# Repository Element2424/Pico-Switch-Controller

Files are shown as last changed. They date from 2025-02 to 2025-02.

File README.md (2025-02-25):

# Pico-USB-Game-Pad-Switch-Controller
DIY Nintendo Switch (and other systems) controller on a Raspberry Pi Pico

## Table of Contents

- [Description](#description)
- [Features](#features)
- [Hardware Limitations](#hardware-limitations)
- [Inspiration](#inspiration)
- [Setup](#setup)
- [Credits](#credits)

---

## Description

This code allows a Raspberry Pi Pico to control a Nintendo Switch (or other console) using button and joystick inputs connected to the Pico's GPIO pins. Once you have the Pico and the code it can be used for a multitude of things. You can edit the code or if that is not a strong point connect the Pico to an other microcontroller to automate mind-numbing tasks in games like shiny hunting in Pokemon, or jumping rope in Mario, ect. If you have access to a 3d printer you can make your own controller or arcade fight stick. I designed and had PCB made for this but it can just as easily be done on proto board and hand soldering wires. This could be use to built cheep easy custom controllers for anyone. I know just enough to get by and used a lot of resources and the projects of others that I will provide links to, so don't criticize the code too harshly. 

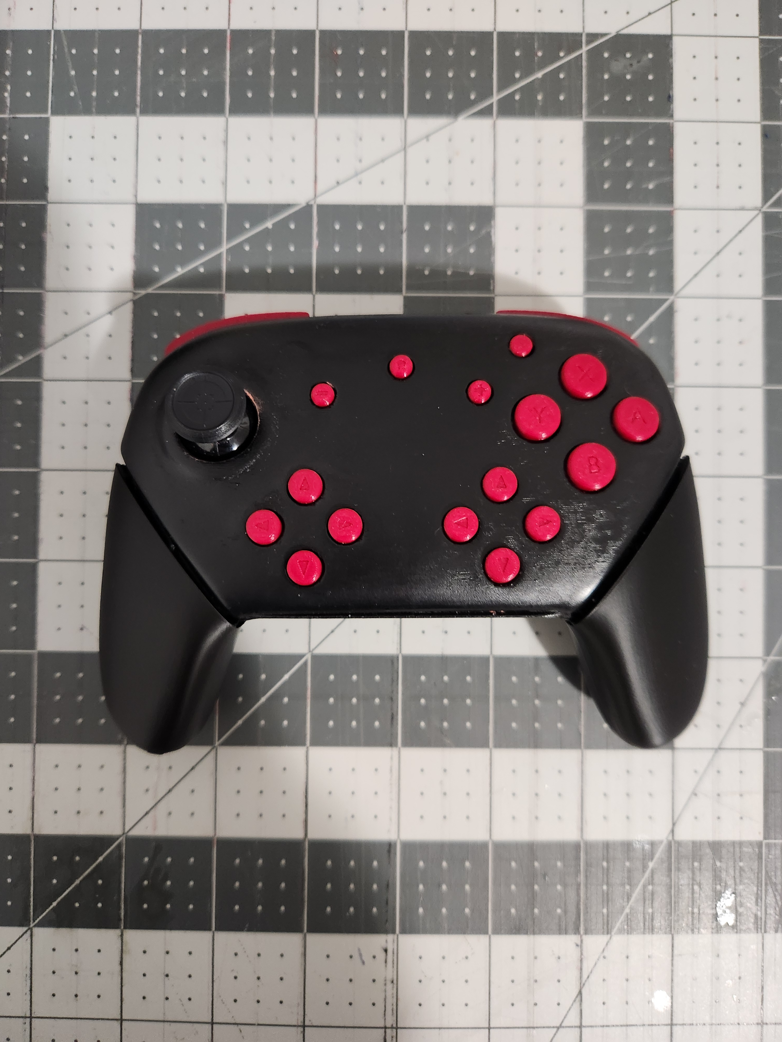
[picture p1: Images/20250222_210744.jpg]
 

## Features

Feature list for this project
- Connects to a Nintendo Switch via USB.
- Will also work on any platform that supports a USB game pad (although some of the buttons may not translate over in the same configuration)
- Fast input responce time for fighting games
- Set up can be as easy as draging and drropping the .uf2 file on to a Pico.
- Scalable inputs for the Left analog stick that can be adjusted to personal preference or to overcome hardware limitations.

## Hardware Limitations

The Pico has 4 analog inputs. Initially I thought this would be great two for the Left Analog Stick X and Y axis, and two for the Right Analog Stick X and Y axis. However it turns out that one of the analog inputs is internal to the RP2040 chip on the Pico and used to read a thermistor. So I was limited to only 3 analog inputs. I choose to use 2 of them for the Left Analog Stick and for the Right Analog Stick I just made them digital buttons. That is not a great solution but was good enough for what I was planning to do. If anyone is feeling ambitious there are extra pins that could be tied to a ADC and read in.

## Inspiration

There have been a lot of things in games that I have thought “It would be nice if this could be automated.” So I started looking around to see if that has been done before. I found a few similar projects that utilize a Teensy board microcontroller to basically do the same thing as this one. Always thought the idea was fun but never wanted to spend the money for one. Not that they are all that expensive but the Pico is 1/4th the cost.  I was able to build a functioning controller for less than 15$ that is less than the cost of a Teensy. I have included a list of parts that I used below. 

- SC0915 Pico 4$
- THB001P Analog Stick 2$
- PTS526SK15SMTR2 LFS Push Buttons 0.13$ x12
- 431256038716 Right Angle Push Button 0.52$ x4

## Setup

To program the Raspberry Pi Pico

1. Hold down the boot sel button on the Pico, and while holding, plug it into your PC via Micro USB cable. (after it has been plugged in you no longer need to hold the boot sel button)
2. Open the Pico in your File Explorer.
3. Download the .uf2 file from this project
4. Drag and drop the .uf2 file to the Pico folder from step 2.
5. Now if you use the the USB cable to connect the Pico to any computer or Nintendo Switch it should register as a controller. That can be tested [here](https://hardwaretester.com/gamepad).
7. Now all that is left is to wire up buttons to the GPIO pins on the Pico and if you want print/build an enclosure for it.

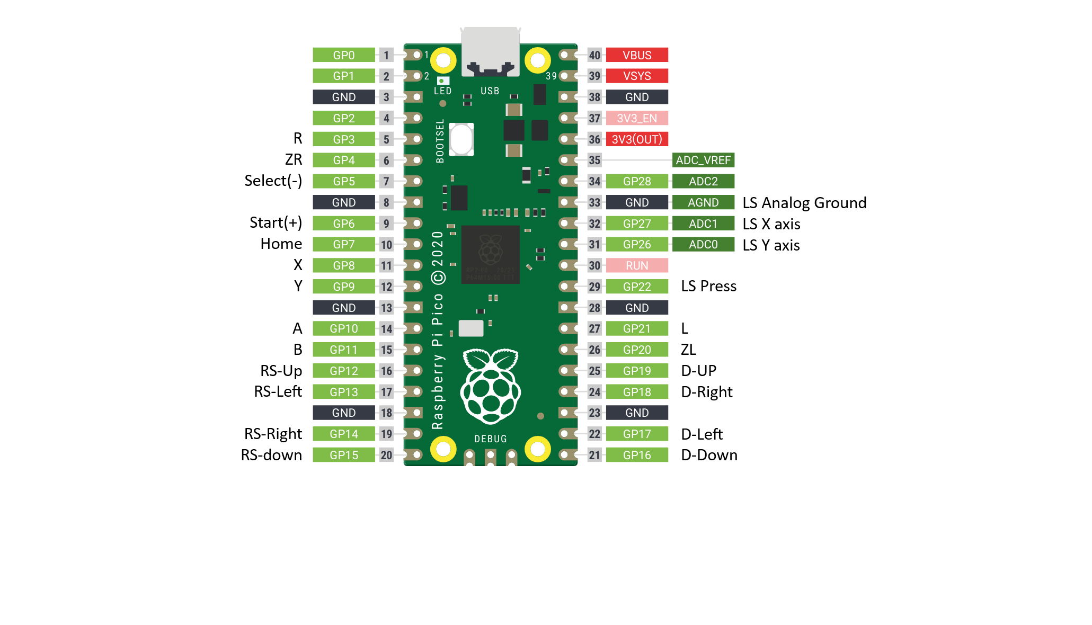
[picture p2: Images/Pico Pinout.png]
 
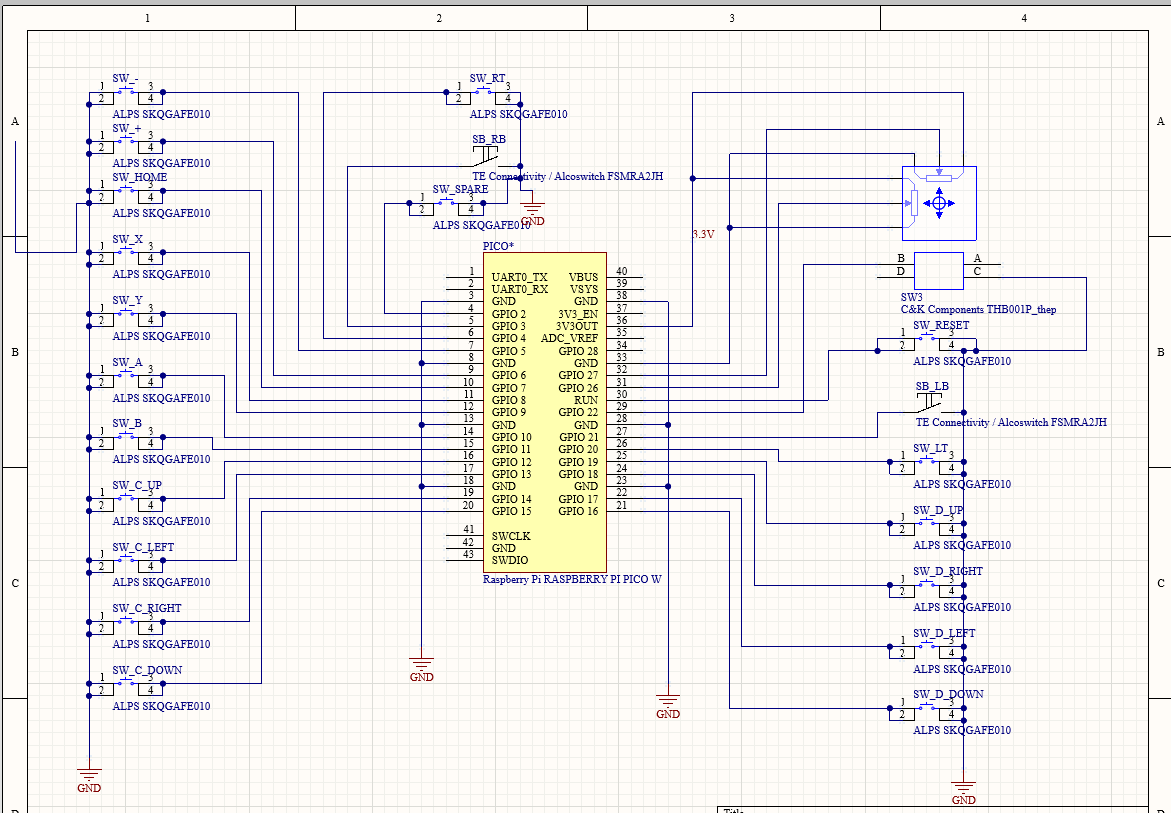
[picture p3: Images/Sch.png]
 

For the left analog stick you should wire the 3.3(Out) (Pin 36) to one end of the analog stick X and Y potentiometers, and the analog ground (pin 33) to the other. Then you should connect the X and Y pins (32 and 31) to their respective wipers.

For all of the other buttons they are set with an internal pull up resistor, this means that you just need to connect their pins to any ground pin to activate them.

I have included the Gerber files that I used to produce the PCB here as well for any who want them. There is also an image of the schematic I used if any want to make their own.

All of the files if you want to 3D print a controller shell and buttons can be found [on my Makerworld upload](https://makerworld.com/en/models/1141897#profileId-1144420), you may have to make an account to download them but they are all free. All of the assembly instructions will be over there as well. The files were too large to upload here. 

If you would like to edit the code I have included all of the source code use to build the .uf2 file as well as the make files that were used. I was using the pico visual studio platform on a windows machine. 

I am more active on my Maker world account, that would be the best place to reach out with questions. 

## Credits 
A lot of the work was already done on the the [Retro Pico Switch](https://github.com/DavidPagels/retro-pico-switch) project. I used this as my starting point, along with the creators and contributors of [TinyUsb](https://github.com/hathach/tinyusb), the [GP2040-CE](https://github.com/OpenStickCommunity/GP2040-CE) project, and the [MPG](https://github.com/OpenStickCommunity/MPG) project.

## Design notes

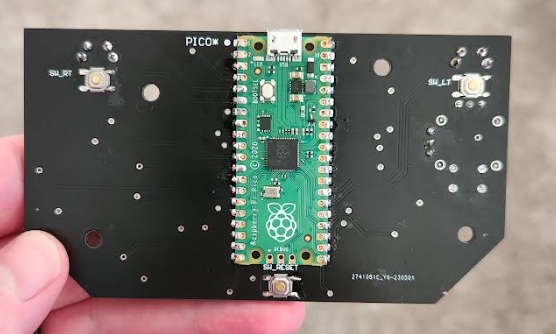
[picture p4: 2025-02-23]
Images/PCB Bottom.png

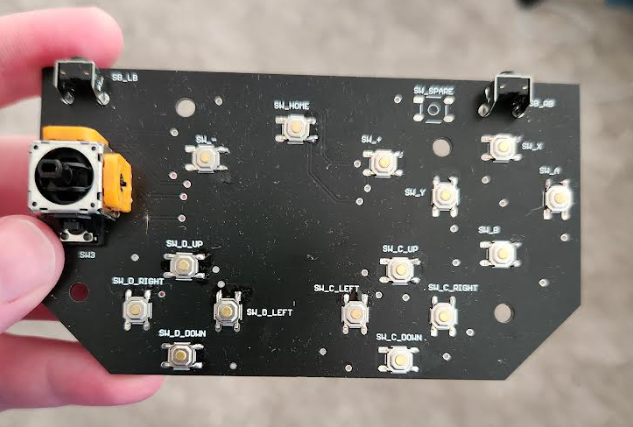
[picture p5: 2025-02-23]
Images/PCB Top.png

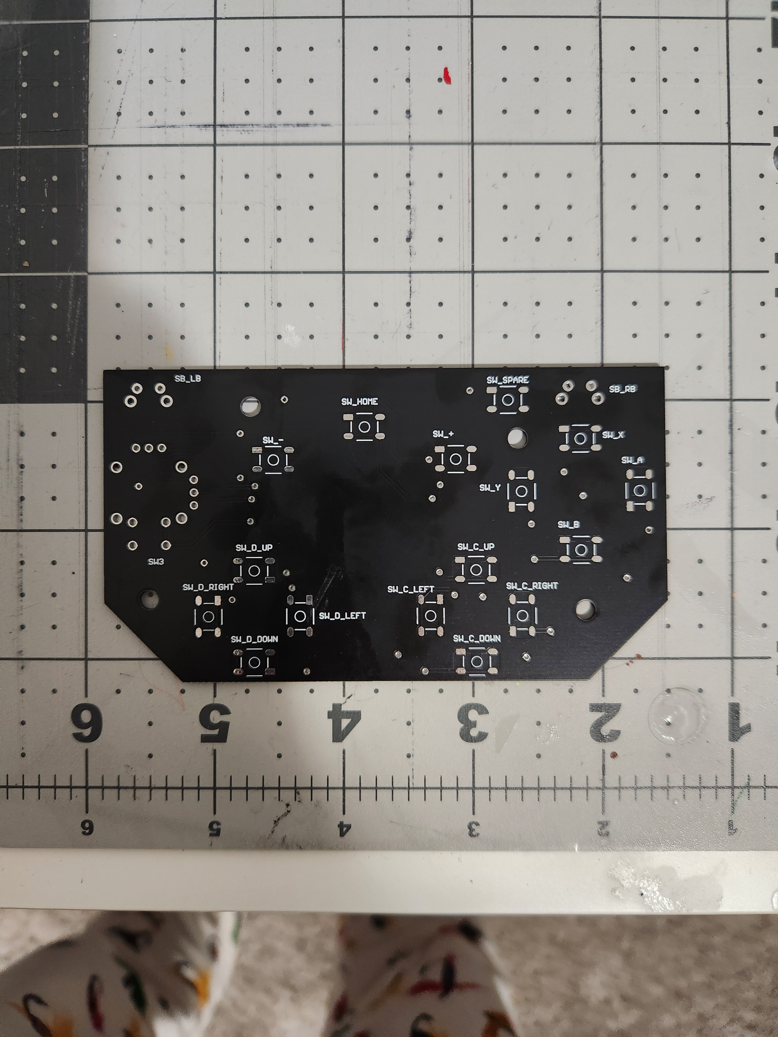
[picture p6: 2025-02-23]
Images/Empty PCB Top.jpg

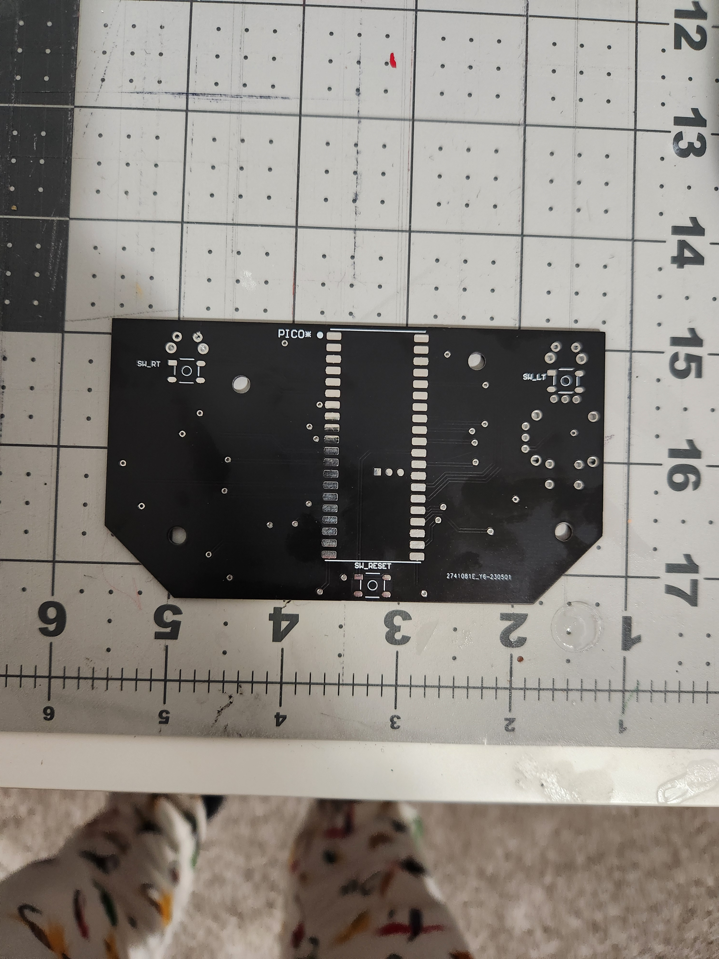
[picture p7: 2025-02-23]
Images/Empty PCB Bottom.jpg

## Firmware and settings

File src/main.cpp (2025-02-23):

#include <stdio.h>
#include <string.h>

#include "GamecubeController.h"
#include "N64Controller.h"
#include "SwitchController.h"
#include "pico/stdlib.h"

#ifdef SWITCH_BLUETOOTH
#include "SwitchBluetooth.h"
#else
#include "SwitchUsb.h"
#endif

#ifdef CONTROLLER_TYPE
#define controllerType CONTROLLER_TYPE
#else
#define controllerType "Switch"
#endif

int main() {
  stdio_init_all();

  Controller *controller;



  if (strcmp(controllerType, "N64") == 0) {
    controller = new N64Controller(18);
  } else if (strcmp(controllerType, "Gamecube") == 0) {
    controller = new GamecubeController(18);
  } else if (strcmp(controllerType, "Switch") == 0) {
    controller = new SwitchController(18);
  }
  controller->init();

#ifdef SWITCH_BLUETOOTH
  SwitchBluetooth::init(controller);
#else
  SwitchUsb switchUsb(controller);
  switchUsb.init();
#endif
}

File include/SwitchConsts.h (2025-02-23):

#ifndef SwitchConsts_h
#define SwitchConsts_h

#include "pico/stdlib.h"

typedef struct __attribute((packed, aligned(1))) {
  uint16_t buttons;
  uint8_t hat;
  uint8_t lx;
  uint8_t ly;
  uint8_t rx;
  uint8_t ry;
  uint8_t vendor;
} SwitchUsbReport;

// HAT report (4 bits)
/*                                  I think the left and right are wrong this is the orginal // Update I was right, at least for the switch these are backwards at least if you are looking at the conntroller
#define SWITCH_USB_HAT_UP 0x00
#define SWITCH_USB_HAT_UPRIGHT 0x01
#define SWITCH_USB_HAT_RIGHT 0x02
#define SWITCH_USB_HAT_DOWNRIGHT 0x03
#define SWITCH_USB_HAT_DOWN 0x04
#define SWITCH_USB_HAT_DOWNLEFT 0x05
#define SWITCH_USB_HAT_LEFT 0x06
#define SWITCH_USB_HAT_UPLEFT 0x07
#define SWITCH_USB_HAT_NOTHING 0x08
*/

#define SWITCH_USB_HAT_UP 0x00
#define SWITCH_USB_HAT_UPRIGHT 0x07
#define SWITCH_USB_HAT_RIGHT 0x06
#define SWITCH_USB_HAT_DOWNRIGHT 0x05
#define SWITCH_USB_HAT_DOWN 0x04
#define SWITCH_USB_HAT_DOWNLEFT 0x03
#define SWITCH_USB_HAT_LEFT 0x02
#define SWITCH_USB_HAT_UPLEFT 0x01
#define SWITCH_USB_HAT_NOTHING 0x08

// Button report (16 bits)
#define SWITCH_USB_MASK_Y (1U << 0)
#define SWITCH_USB_MASK_B (1U << 1)
#define SWITCH_USB_MASK_A (1U << 2)
#define SWITCH_USB_MASK_X (1U << 3)
#define SWITCH_USB_MASK_L (1U << 4)
#define SWITCH_USB_MASK_R (1U << 5)
#define SWITCH_USB_MASK_ZL (1U << 6)
#define SWITCH_USB_MASK_ZR (1U << 7)
#define SWITCH_USB_MASK_MINUS (1U << 8)
#define SWITCH_USB_MASK_PLUS (1U << 9)
#define SWITCH_USB_MASK_L3 (1U << 10)
#define SWITCH_USB_MASK_R3 (1U << 11)
#define SWITCH_USB_MASK_HOME (1U << 12)
#define SWITCH_USB_MASK_CAPTURE (1U << 13)

// Switch analog sticks only report 8 bits
#define SWITCH_USB_JOYSTICK_MIN 0x00
#define SWITCH_USB_JOYSTICK_MID 0x80
#define SWITCH_USB_JOYSTICK_MAX 0xFF

static const uint8_t switch_usb_string_language[] = {0x09, 0x04};
static const uint8_t switch_usb_string_manufacturer[] = "PICO SWITCH PRO.";
static const uint8_t switch_usb_string_product[] = "J24 CONTROLLER";
static const uint8_t switch_usb_string_version[] = "1.0";

static const uint8_t *switch_usb_string_descriptors[] = {
    switch_usb_string_language, switch_usb_string_manufacturer,
    switch_usb_string_product, switch_usb_string_version};

static const uint8_t switch_usb_device_descriptor[] = {
    0x12,        // bLength
    0x01,        // bDescriptorType (Device)
    0x00, 0x02,  // bcdUSB 2.00
    0x00,  // bDeviceClass (Use class information in the Interface Descriptors)
    0x00,  // bDeviceSubClass
    0x00,  // bDeviceProtocol
    0x40,  // bMaxPacketSize0 64
    0x0D, 0x0F,  // idVendor 0x0F0D
    0x92, 0x00,  // idProduct 0x92
    0x00, 0x01,  // bcdDevice 2.00
    0x01,        // iManufacturer (String Index)
    0x02,        // iProduct (String Index)
    0x00,        // iSerialNumber (String Index)
    0x01,        // bNumConfigurations 1
};

static const uint8_t switch_usb_hid_descriptor[] = {
    0x09,        // bLength
    0x21,        // bDescriptorType (HID)
    0x11, 0x01,  // bcdHID 1.11
    0x00,        // bCountryCode
    0x01,        // bNumDescriptors
    0x22,        // bDescriptorType[0] (HID)
    0x56, 0x00,  // wDescriptorLength[0] 86
};

static const uint8_t switch_usb_configuration_descriptor[] = {
    0x09,        // bLength
    0x02,        // bDescriptorType (Configuration)
    0x29, 0x00,  // wTotalLength 41
    0x01,        // bNumInterfaces 1
    0x01,        // bConfigurationValue
    0x00,        // iConfiguration (String Index)
    0x80,        // bmAttributes
    0xFA,        // bMaxPower 500mA

    0x09,  // bLength
    0x04,  // bDescriptorType (Interface)
    0x00,  // bInterfaceNumber 0
    0x00,  // bAlternateSetting
    0x02,  // bNumEndpoints 2
    0x03,  // bInterfaceClass
    0x00,  // bInterfaceSubClass
    0x00,  // bInterfaceProtocol
    0x00,  // iInterface (String Index)

    0x09,        // bLength
    0x21,        // bDescriptorType (HID)
    0x11, 0x01,  // bcdHID 1.11
    0x00,        // bCountryCode
    0x01,        // bNumDescriptors
    0x22,        // bDescriptorType[0] (HID)
    0x56, 0x00,  // wDescriptorLength[0] 86

    0x07,        // bLength
    0x05,        // bDescriptorType (Endpoint)
    0x02,        // bEndpointAddress (OUT/H2D)
    0x03,        // bmAttributes (Interrupt)
    0x40, 0x00,  // wMaxPacketSize 64
    0x01,        // bInterval 1 (unit depends on device speed)

    0x07,        // bLength
    0x05,        // bDescriptorType (Endpoint)
    0x81,        // bEndpointAddress (IN/D2H)
    0x03,        // bmAttributes (Interrupt)
    0x40, 0x00,  // wMaxPacketSize 64
    0x01,        // bInterval 1 (unit depends on device speed)
};
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

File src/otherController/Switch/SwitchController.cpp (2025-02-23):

#include "SwitchController.h"

#include "Controller.pio.h"
#include "pico/stdlib.h"

//below this are my includes
#include <stdio.h>
#include "pico.h"
#include "hardware/structs/adc.h"
//#include "pico/stdlib.h"
#include "hardware/gpio.h"
#include "hardware/adc.h"



void SwitchController::init() {
  // init led pin and set it to an outpit
    gpio_init(LED_PIN);
    gpio_set_dir(LED_PIN, GPIO_OUT);

    //init all of the digital input button pins and have them be pulled high by defalt
    for(int i = 0; i <= 22; i++){
        gpio_init(i);
        gpio_set_dir(i, GPIO_IN);
        gpio_pull_up(i);
    }
    
    adc_init(); //init adc functionality
    adc_gpio_init(ANALOG_X_PIN); // sets gpio as high impedance, no pullups ect
    //adc_select_input(0); // selects adc0 for analog X 
    adc_gpio_init(ANALOG_Y_PIN); // sets gpio as high impedance, no pullups ect
    //adc_select_input(1);  // selects adc1 for analog Y

    sleep_us(200); // not sure if this is needed
    
}

void SwitchController::ReadPins(){
   
}

void SwitchController::updateState() {
  //reads and stores all of the digitial GIOP pins 
  _ButtonReport = ~gpio_get_all(); // inverted because the pins are pulled high
  
  // reads and stores the values for the left stick analog values
  adc_select_input(0); // selects adc0 for analog X 
  _LS_X = adc_read();
  adc_select_input(1); // selects adc1 for analog Y 
  _LS_Y = adc_read();

}

void SwitchController::getSwitchUsbReport(SwitchUsbReport *switchUsbReport) {

  updateState();
  gpio_put(LED_PIN, false);
 // if(SWITCH_C_MASK & _ButtonReport ){gpio_put(LED_PIN, true);}
  if(PIN_MASK_2 & _ButtonReport ){gpio_put(LED_PIN, true);}

  switchUsbReport->hat = SWITCH_USB_HAT_NOTHING;
  switchUsbReport->rx = SWITCH_USB_JOYSTICK_MID;
  switchUsbReport->ry = SWITCH_USB_JOYSTICK_MID;

  /*
  uint16_t test = 3;

  switchUsbReport->buttons = 0;
  gpio_put(led_pin, false);

    if(gpio_get(16) == false){
      switchUsbReport->buttons += 4;
      gpio_put(led_pin, true);
    }
    if (gpio_get(17) == false){
      switchUsbReport->buttons += 2;
      gpio_put(led_pin, true);
    }
    */
  
  // Updating digital buttons 
  switchUsbReport->buttons =
      (PIN_MASK_20 & _ButtonReport ? SWITCH_USB_MASK_ZL : 0) |
      (PIN_MASK_21 & _ButtonReport ? SWITCH_USB_MASK_L : 0) |
      (PIN_MASK_4 & _ButtonReport ? SWITCH_USB_MASK_ZR : 0) |
      (PIN_MASK_3 & _ButtonReport ? SWITCH_USB_MASK_R : 0) |
      (PIN_MASK_9 & _ButtonReport ? SWITCH_USB_MASK_Y : 0) |
      (PIN_MASK_8 & _ButtonReport ? SWITCH_USB_MASK_X : 0) |
      (PIN_MASK_11 & _ButtonReport ? SWITCH_USB_MASK_B : 0) |
      (PIN_MASK_10 & _ButtonReport ? SWITCH_USB_MASK_A : 0) |
      (PIN_MASK_7 & _ButtonReport ? SWITCH_USB_MASK_HOME : 0) |
      (PIN_MASK_5 & _ButtonReport ? SWITCH_USB_MASK_MINUS : 0) |
      (PIN_MASK_6 & _ButtonReport ? SWITCH_USB_MASK_PLUS : 0) |
      (PIN_MASK_22 & _ButtonReport ? SWITCH_USB_MASK_L3 : 0);
      

      
  // Setting D PAD
  switch (SWITCH_DPAD_MASK & _ButtonReport) {
    case SWITCH_DPAD_UP:
      switchUsbReport->hat = SWITCH_USB_HAT_UP;
      break;
    case SWITCH_DPAD_UP_RIGHT:
      switchUsbReport->hat = SWITCH_USB_HAT_UPRIGHT;
      break;
    case SWITCH_DPAD_RIGHT:
      switchUsbReport->hat = SWITCH_USB_HAT_RIGHT;
      break;
    case SWTICH_DPAD_DOWN_RIGHT:
      switchUsbReport->hat = SWITCH_USB_HAT_DOWNRIGHT;
      break;
    case SWITCH_DPAD_DOWN:
      switchUsbReport->hat = SWITCH_USB_HAT_DOWN;
      break;
    case SWITCH_DPAD_DOWN_LEFT:
      switchUsbReport->hat = SWITCH_USB_HAT_DOWNLEFT;
      break;
    case SWITCH_DPAD_LEFT:
      switchUsbReport->hat = SWITCH_USB_HAT_LEFT;
      break;
    case SWITCH_DPAD_UP_LEFT:
      switchUsbReport->hat = SWITCH_USB_HAT_UPLEFT;
      break;
  }
  // Updating C Stick
  //switchUsbReport->rx = SWITCH_USB_JOYSTICK_MID;
  //switchUsbReport->ry = SWITCH_USB_JOYSTICK_MID;
  switch (SWITCH_C_MASK & _ButtonReport) {
    case PIN_MASK_12:
      switchUsbReport->ry = SWITCH_USB_JOYSTICK_MIN;
      break;
    case PIN_MASK_15:
      switchUsbReport->ry = SWITCH_USB_JOYSTICK_MAX;
      break;
    case PIN_MASK_13:
      switchUsbReport->rx = SWITCH_USB_JOYSTICK_MIN;
      break;
    case PIN_MASK_14:
      switchUsbReport->rx = SWITCH_USB_JOYSTICK_MAX;
      break;
  }

  //updating Left Stick

    uint16_t _LS_X_pos = 255-(_LS_Zero_Factor * _LS_Y); // not sure what error lead to these needing to be switched byt x is y and y is x
    uint16_t _LS_Y_pos = 255-(_LS_Zero_Factor * _LS_X);
/*
    if(_LS_X_pos > (SWITCH_USB_JOYSTICK_MID + _LS_Dead_Zone))
    {
      _LS_X_pos = _LS_X_pos * (1 + _LS_X_Scale_Factor_P);
    }

    else if(_LS_X_pos < (SWITCH_USB_JOYSTICK_MID - _LS_Dead_Zone))
    {
      _LS_X_pos = _LS_X_pos * (1 - _LS_X_Scale_Factor_N);
    }

    else {_LS_X_pos = SWITCH_USB_JOYSTICK_MID;}

    if(_LS_Y_pos > (SWITCH_USB_JOYSTICK_MID + _LS_Dead_Zone))
    {
      _LS_Y_pos = _LS_Y_pos * (1 + _LS_Y_Scale_Factor_P);
    }

    else if(_LS_Y_pos < (SWITCH_USB_JOYSTICK_MID - _LS_Dead_Zone))
    {
      _LS_Y_pos = _LS_Y_pos * (1 - _LS_Y_Scale_Factor_N);
    }

    else {_LS_Y_pos = SWITCH_USB_JOYSTICK_MID;}
*/
    if(_LS_X_pos > (SWITCH_USB_JOYSTICK_MID + _LS_Dead_Zone))
    {
      _LS_X_pos = _LS_X_pos + ((_LS_X_pos - SWITCH_USB_JOYSTICK_MID ) * _LS_X_Scale_Factor_P); 
    }
     else if(_LS_X_pos < (SWITCH_USB_JOYSTICK_MID - _LS_Dead_Zone))
    {
      _LS_X_pos = _LS_X_pos + ((_LS_X_pos - SWITCH_USB_JOYSTICK_MID) * _LS_X_Scale_Factor_N); 
    }
    else {_LS_X_pos = SWITCH_USB_JOYSTICK_MID;}

    

    if(_LS_Y_pos > (SWITCH_USB_JOYSTICK_MID + _LS_Dead_Zone))
    {
      _LS_Y_pos = _LS_Y_pos + ((_LS_Y_pos - SWITCH_USB_JOYSTICK_MID ) * _LS_Y_Scale_Factor_P); 
    }
    else if(_LS_Y_pos < (SWITCH_USB_JOYSTICK_MID - _LS_Dead_Zone))
    {
      _LS_Y_pos = _LS_Y_pos + ((_LS_Y_pos - SWITCH_USB_JOYSTICK_MID ) * _LS_Y_Scale_Factor_N); 
    }
    else {_LS_Y_pos = SWITCH_USB_JOYSTICK_MID;}


    if (_LS_X_pos > SWITCH_USB_JOYSTICK_MAX)
    {
        _LS_X_pos = SWITCH_USB_JOYSTICK_MAX;
    }

    if (_LS_X_pos < SWITCH_USB_JOYSTICK_MIN)
    {
        _LS_X_pos = SWITCH_USB_JOYSTICK_MIN;
    }

    if (_LS_Y_pos > SWITCH_USB_JOYSTICK_MAX)
    {
        _LS_Y_pos = SWITCH_USB_JOYSTICK_MAX;
    }

    if (_LS_Y_pos < SWITCH_USB_JOYSTICK_MIN)
    {
        _LS_Y_pos = SWITCH_USB_JOYSTICK_MIN;
    }


    switchUsbReport->ly = _LS_Y_pos;
    switchUsbReport->lx = _LS_X_pos;
  /*
  // scale for joystick insensitivity if needed
  // https://n64squid.com/n64-joystick-360-degrees/
  switchUsbReport->lx =
      convertToSwitchUsbJoystick(_controllerState[2], &_minX, &_maxX);
  switchUsbReport->ly =
      convertToSwitchUsbJoystick(-_controllerState[3], &_minY, &_maxY);*/
  //return;
  
}
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

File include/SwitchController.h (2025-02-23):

#ifndef SwitchController_h
#define SwitchController_h

#include "Controller.h"

#define ANALOG_Y_PIN 26
#define ANALOG_X_PIN 27

#define LED_PIN 25

#define LS_PIN 22
#define LB_PIN 21
#define LT_PIN 20

#define D_UP_PIN 19
#define D_RIGHT_PIN 18 
#define D_LEFT_PIN 17
#define D_DOWN_PIN 16 

#define C_DOWN_PIN 15 
#define C_RIGHT_PIN 14
#define C_LEFT_PIN 13
#define C_UP_PIN 12

#define B_PIN 11
#define A_PIN 10
#define Y_PIN 9
#define X_PIN 8

#define HOME_PIN 7
#define START_PIN 6
#define SELECT_PIN 5

#define RT_PIN 4
#define RB_PIN 3

#define SPARE_PIN 2

#define PIN_MASK_0  (1U << 0)
#define PIN_MASK_1  (1U << 1)
#define PIN_MASK_2  (1U << 2)
#define PIN_MASK_3  (1U << 3)
#define PIN_MASK_4  (1U << 4)
#define PIN_MASK_5  (1U << 5)
#define PIN_MASK_6  (1U << 6)
#define PIN_MASK_7  (1U << 7)
#define PIN_MASK_8  (1U << 8)
#define PIN_MASK_9  (1U << 9)
#define PIN_MASK_10 (1U << 10)
#define PIN_MASK_11 (1U << 11)
#define PIN_MASK_12 (1U << 12)
#define PIN_MASK_13 (1U << 13)
#define PIN_MASK_14 (1U << 14)
#define PIN_MASK_15 (1U << 15)
#define PIN_MASK_16 (1U << 16)
#define PIN_MASK_17 (1U << 17)
#define PIN_MASK_18 (1U << 18)
#define PIN_MASK_19 (1U << 19)
#define PIN_MASK_20 (1U << 20)
#define PIN_MASK_21 (1U << 21)
#define PIN_MASK_22 (1U << 22)

#define SWITCH_DPAD_MASK 0xF0000
#define SWITCH_DPAD_UP 0x80000
#define SWITCH_DPAD_UP_RIGHT 0xC0000
#define SWITCH_DPAD_UP_LEFT 0xA0000
#define SWITCH_DPAD_DOWN 0x10000
#define SWTICH_DPAD_DOWN_RIGHT 0x50000
#define SWITCH_DPAD_DOWN_LEFT 0x30000
#define SWITCH_DPAD_RIGHT 0x40000
#define SWITCH_DPAD_LEFT 0x20000

#define SWITCH_C_MASK 0xF000







class SwitchController : public Controller {
 public:
  SwitchController(uint8_t pin) : Controller(pin, 4){};
  void init();

  void getSwitchUsbReport(SwitchUsbReport *switchUsbReport);
  uint16_t convertToSwitchUsbJoystick(int8_t axisPos, double *minAxis,
                                      double *maxAxis);
  void getSwitchBtReport(SwitchBtReport *switchBtReport);
  uint16_t convertToSwitchBtJoystick(int8_t axisPos, double *minAxis,
                                     double *maxAxis);



  void ReadPins();

 private:
  void updateState();


  const float _LS_Scale_Factor = .06; // was 0.06227
  const float _LS_Zero_Factor = .0605; // was 0.06227
  const float _LS_X_Scale_Factor_P = .54; // you may need to adjust these values, you want your analaog stick to hit the max 
  const float _LS_Y_Scale_Factor_P = .51; // you may need to adjust these values, you want your analaog stick to hit the max
  const float _LS_X_Scale_Factor_N = .39; //you may need to adjust these values, you want your analaog stick to hit the min
  const float _LS_Y_Scale_Factor_N = .45; //you may need to adjust these values, you want your analaog stick to hit the min
  const float _LS_Dead_Zone = 9; 
  uint32_t _ButtonReport;
  uint16_t _LS_X = 0;
  uint16_t _LS_Y = 0; 
  
};



#endif
